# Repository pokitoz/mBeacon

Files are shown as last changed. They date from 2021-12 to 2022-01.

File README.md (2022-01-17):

# mBeacon

mBeacon

## Antenna

- No angle on the trace
- Vias should surround the track and the antenna to apply a shielding
- It is best to avoid the use FR4 stack layer
  - As this is not controled and epsilon can vary. 
  - HR370 isola is better to control the impedence

To check the 50Ohm, use the too AppCAD or https://saturnpcb.com/saturn-pcb-toolkit/
- Go to `Tools > DRC...` 
- find layer stack in eagle..
- copper is selected when ordering. Check the manufacturer webite: https://jlcpcb.com/capabilities/Capabilities
- stack manager: Isolation height and copper height Track height.

## Manufacturing

- File > Generate CAM data
  - Export to .zip and upload to manufacturing site
- For jlcpcb, BOM and CPL needs to be generated: https://support.jlcpcb.com/article/132-how-to-generate-bom-and-cpl-from-eagle-cad-automatically

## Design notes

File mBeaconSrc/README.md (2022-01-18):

# mBeacon

## Project setup

- Do not have Spaces in the path of the project
- Based on platformio: `https://platformio.org/install/ide?install=vscode`, use VSCode and import the project
- Zephyr version can be found in `C:\.platformio\packages\framework-zephyr\VERSION`.
- Look for `https://docs.platformio.org/en/latest/frameworks/zephyr.html?utm_source=docs.zephyrproject.org#configuration`
  To get more details on how to configure the workspace.
- `make menuconfig`, if arrows do not work, use "j" and "k".

## Run the program

Logs can be extracted using J-Link RTT viewer
It won't start until it is connected. Configuration is nRF52832_xxAA

## Files

zephyr: contains all the necessary information for the OS:

- DTS overlay for adding the support of the sensors
- conf: For adding or removing some parts of the OS
- Contains the main top level CMake file

src: Source of the project, all the .c files (from platform IO)

include: Includes of the project, all the .h files (from platform IO)

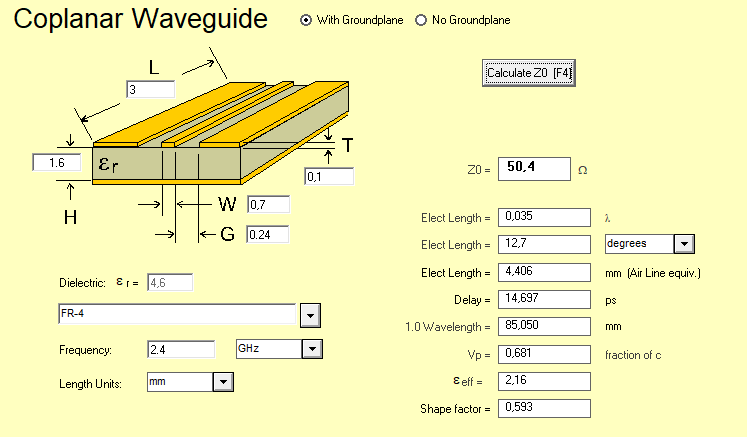
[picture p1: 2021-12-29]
coplanar.png

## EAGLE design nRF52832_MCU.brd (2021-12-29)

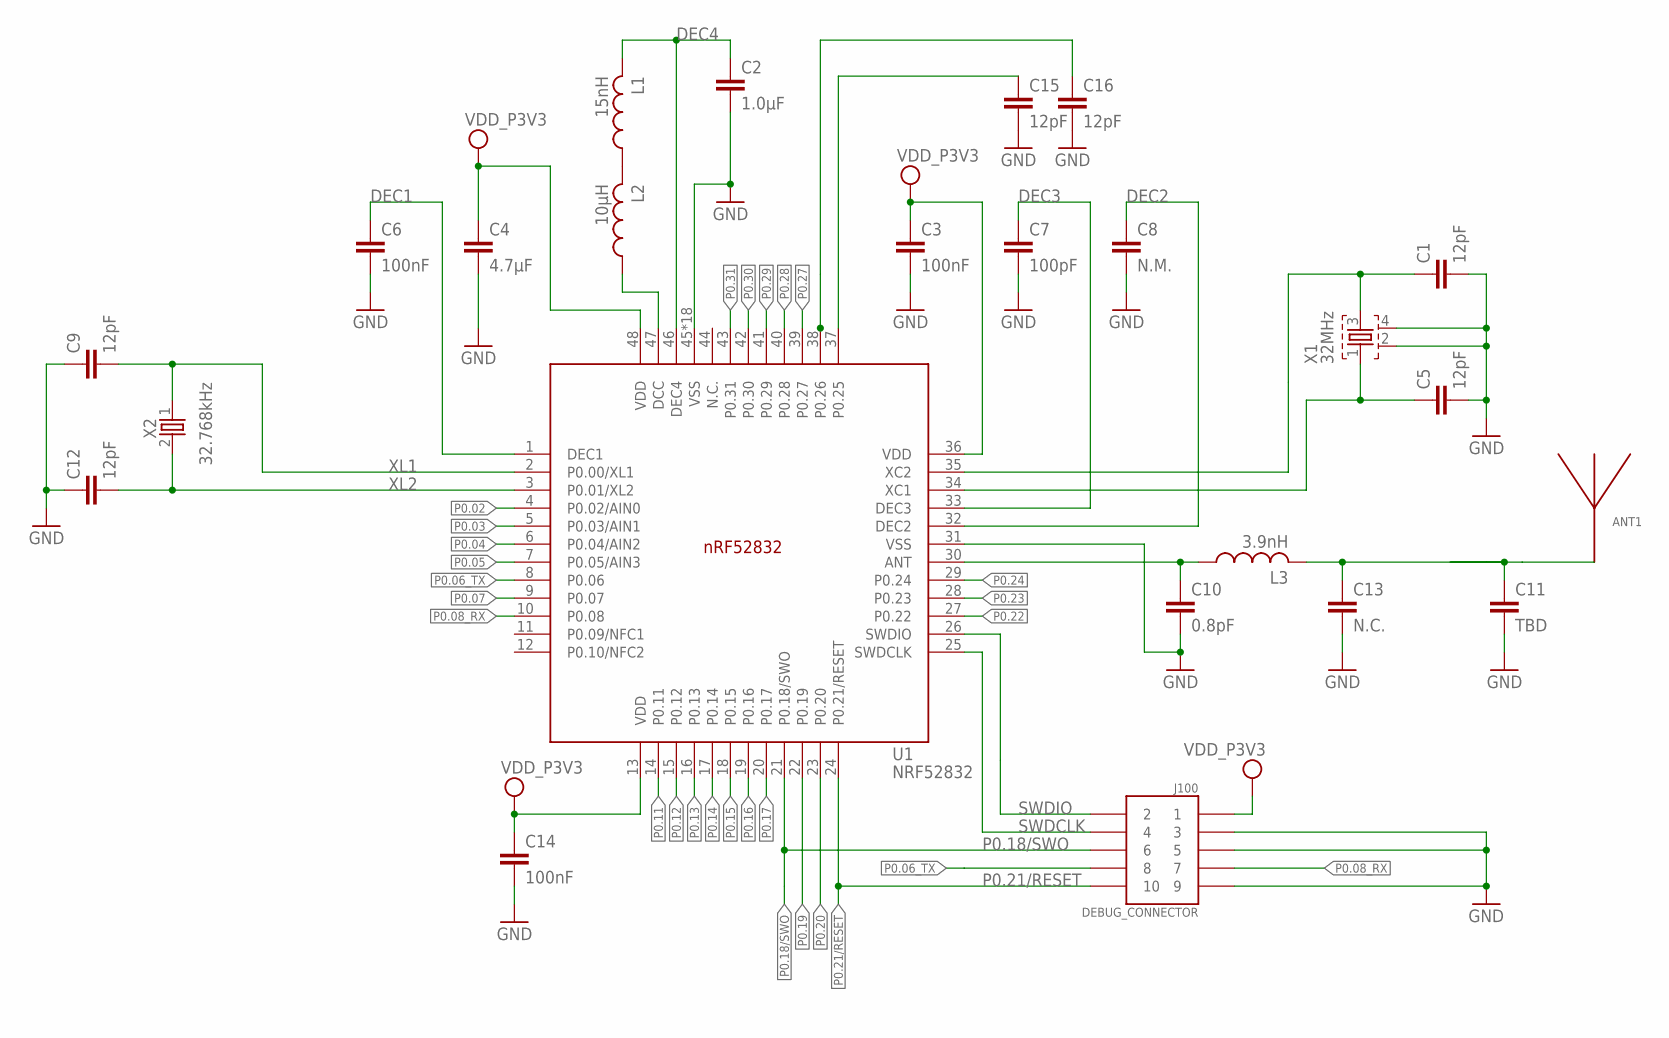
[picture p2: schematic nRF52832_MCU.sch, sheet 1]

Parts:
ANT1: ANTENNA_QUARTER-WAVE_MONOPOLE_MEANDERED_LEFT; QWMP_MEANDERED_LEFT_+6
C1, C5, C9, C12, C15, C16: 12pF; RESC0402_N
C2: 1.0µF; RESC0603_N
C3, C6, C14: 100nF; RESC0402_N
C4: 4.7µF; RESC0603_N
C7: 100pF; RESC0402_N
C8: N.M.; RESC0402_N
C10: 0.8pF; RESC0402_N
C11: TBD; RESC0402_N
C13: N.C.; RESC0402_N
J100: DEBUG_CONNECTOR; HDRV127P5X2-10_N
L1: 15nH; RESC0402_N
L2: 10µH; RESC0603_N
L3: 3.9nH; RESC0402_N
U1: NRF52832; QFN40P600X600X90-48_N
X1: 32MHz; BT-XTAL_2016_N
X2: 32.768kHz; XTAL_3215_N

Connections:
ANT: C10.1, L3.1, U1.30 (ANT)
DEC1: C6.1, U1.1 (DEC1)
DEC2: C8.1, U1.32 (DEC2)
DEC3: C7.1, U1.33 (DEC3)
DEC4: C2.1, L1.2, U1.46 (DEC4)
unnamed: L1.1, L2.2
unnamed: C1.1, U1.35 (XC2), X1.3
unnamed: L2.1, U1.47 (DCC)
unnamed: ANT1.P$1, C11.1, C13.1, L3.2
unnamed 14: C1.2, C2.2, C3.2, C4.2, C5.2, C6.2, C7.2, C8.2, C9.1, C10.2, C11.2, C12.1, C13.2, C14.2, C15.2, C16.2, J100.3, J100.5, J100.9, U1.31 (VSS), U1.45 (VSS), U1.PAD (VSS), U1.PAD@VIA01 (VSS), U1.PAD@VIA02 (VSS), U1.PAD@VIA03 (VSS), U1.PAD@VIA04 (VSS), U1.PAD@VIA05 (VSS), U1.PAD@VIA06 (VSS), U1.PAD@VIA07 (VSS), U1.PAD@VIA08 (VSS), U1.PAD@VIA09 (VSS), U1.PAD@VIA10 (VSS), U1.PAD@VIA11 (VSS), U1.PAD@VIA12 (VSS), U1.PAD@VIA13 (VSS), U1.PAD@VIA14 (VSS), U1.PAD@VIA15 (VSS), U1.PAD@VIA16 (VSS), X1.2, X1.4; also elsewhere on the board
P0.02: U1.4 (P0.02/AIN0)
P0.03: U1.5 (P0.03/AIN1)
P0.04: U1.6 (P0.04/AIN2); also elsewhere on the board
P0.05: U1.7 (P0.05/AIN3); also elsewhere on the board
P0.06_TX: J100.8, U1.8 (P0.06)
P0.07: U1.9 (P0.07); also elsewhere on the board
P0.08_RX: J100.7, U1.10 (P0.08)
P0.11: U1.14 (P0.11)
P0.12: U1.15 (P0.12)
P0.13: U1.16 (P0.13); also elsewhere on the board
P0.14: U1.17 (P0.14); also elsewhere on the board
P0.15: U1.18 (P0.15)
P0.16: U1.19 (P0.16)
P0.17: U1.20 (P0.17)
P0.18/SWO: J100.6, U1.21 (P0.18/SWO)
P0.19: U1.22 (P0.19)
P0.20: U1.23 (P0.20)
P0.21/RESET: J100.10, U1.24 (P0.21/RESET)
P0.22: U1.27 (P0.22)
P0.23: U1.28 (P0.23)
P0.24: U1.29 (P0.24)
P0.25: C15.1, U1.37 (P0.25)
P0.26: C16.1, U1.38 (P0.26)
P0.27: U1.39 (P0.27)
P0.28: U1.40 (P0.28)
P0.29: U1.41 (P0.29)
P0.30: U1.42 (P0.30)
P0.31: U1.43 (P0.31)
SWDCLK: J100.4, U1.25 (SWDCLK)
SWDIO: J100.2, U1.26 (SWDIO)
VDD_P3V3: C3.1, C4.1, C14.1, J100.1, U1.13 (VDD), U1.36 (VDD), U1.48 (VDD); also elsewhere on the board
X1: C5.1, U1.34 (XC1), X1.1
XL1: C9.2, U1.2 (P0.00/XL1), X2.1
XL2: C12.2, U1.3 (P0.01/XL2), X2.2

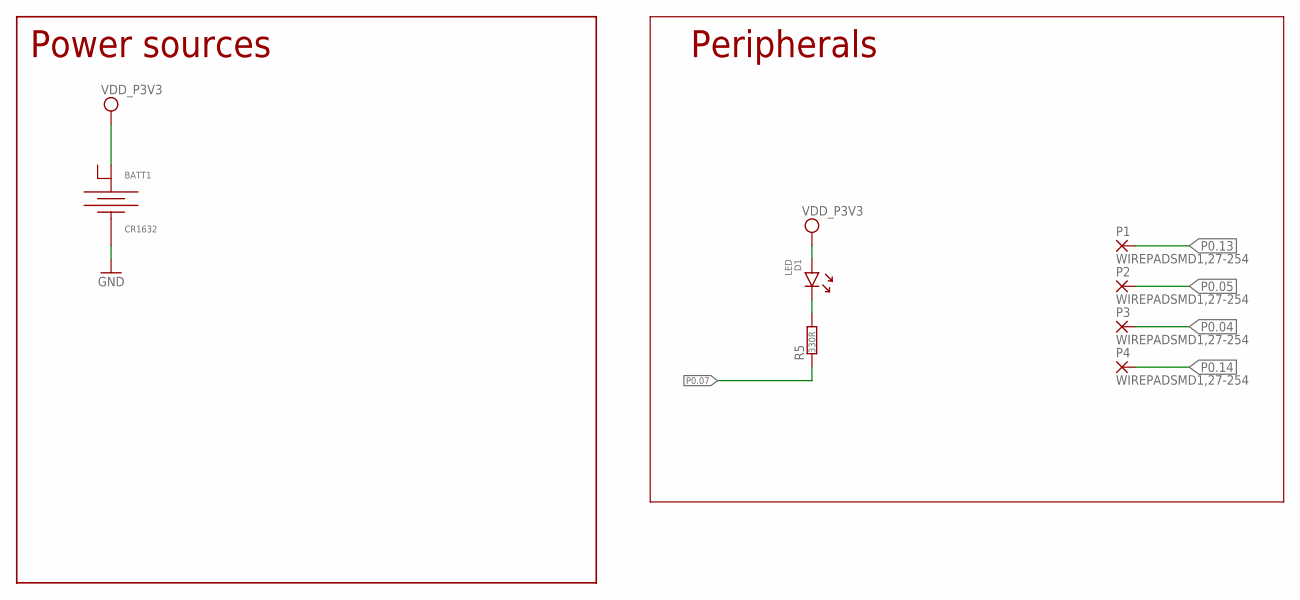
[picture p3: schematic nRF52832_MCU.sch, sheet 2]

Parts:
BATT1: CR1632; CR1632_HOLDER_TH
D1: LED; DIOC0603_N
P1, P2, P3, P4: WIREPADSMD1,27-254; SMD1,27-2,54
R5: 330R; RESC0402_N

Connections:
unnamed: D1.1 (C), R5.2
unnamed 14: BATT1.1 (-); also elsewhere on the board
P0.04: P3.1; also elsewhere on the board
P0.05: P2.1; also elsewhere on the board
P0.07: R5.1; also elsewhere on the board
P0.13: P1.1; also elsewhere on the board
P0.14: P4.1; also elsewhere on the board
VDD_P3V3: BATT1.2 (+), D1.2 (A); also elsewhere on the board

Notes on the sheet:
Power sources
Peripherals

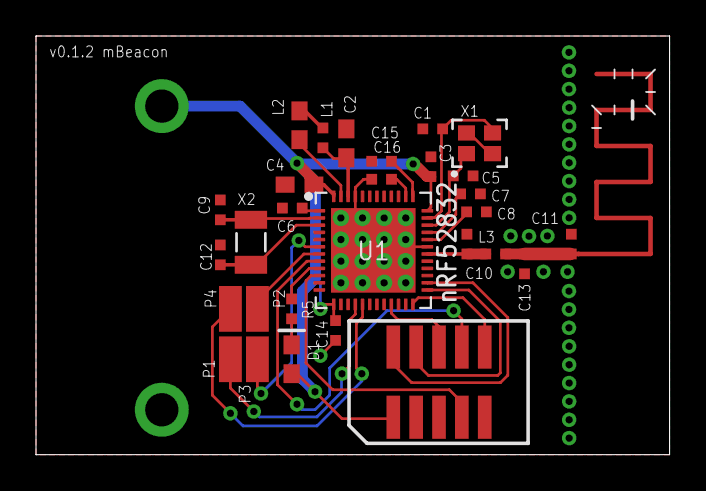
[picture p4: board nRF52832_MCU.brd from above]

Board: 2 copper layers, 35.2 x 23.3 mm, 31 parts (1 on the bottom side), 28 nets.

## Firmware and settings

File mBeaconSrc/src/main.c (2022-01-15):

#include <zephyr.h>
#include <sys/printk.h>
#include <device.h>
#include <drivers/gpio.h>
#include <bluetooth/bluetooth.h>
#include <bluetooth/hci.h>

#define DEVICE_NAME CONFIG_BT_DEVICE_NAME
#define DEVICE_NAME_LEN (sizeof(DEVICE_NAME) - 1)

#define LED0_NODE DT_ALIAS(led0)

#if DT_NODE_HAS_STATUS(LED0_NODE, okay)
#define LED0  DT_GPIO_LABEL(LED0_NODE, gpios)
#define PIN  DT_GPIO_PIN(LED0_NODE, gpios)
#define FLAGS  DT_GPIO_FLAGS(LED0_NODE, gpios)
#else
#error "No LED0"
#endif
#define MIN_PERIOD_USEC  (USEC_PER_SEC / 64U)
#define MAX_PERIOD_USEC  USEC_PER_SEC
#define SLEEP_TIME_MS   1000

static uint8_t mfg_data[] = {
  0xda, 0x09, // Nagra ID code
  0x64, // Battery level
  0xFF, 0xFA, 0xAC, 0xFF, 0xDE, 0xAD, // Mac
  'A', 'n', 'T', 'Z', 'o', 'n', '-', 'E', '8', // Whitelist
  0xb0, 0x01
};


// Advertizing should be on 31 bytes max
static struct bt_data ad[] = {
  BT_DATA_BYTES(BT_DATA_FLAGS, (BT_LE_AD_GENERAL | BT_LE_AD_NO_BREDR)),
  BT_DATA_BYTES(BT_DATA_UUID16_ALL, 0xFF, 0xF1),
  BT_DATA(BT_DATA_MANUFACTURER_DATA, mfg_data, sizeof(mfg_data))
};

/* Set Scan Response data */
static const struct bt_data sd[] = {
  BT_DATA(BT_DATA_NAME_COMPLETE, DEVICE_NAME, DEVICE_NAME_LEN),
};

static void bt_ready(int err)
{
  char addr_s[BT_ADDR_LE_STR_LEN];
  bt_addr_le_t addr = {0};
  size_t count = 1;

  if (err) {
    printk("Bluetooth init failed (err %d)\n", err);
    return;
  }

  printk("Bluetooth initialized\n");

  /* Start advertising */
  err = bt_le_adv_start(BT_LE_ADV_NCONN_IDENTITY, ad, ARRAY_SIZE(ad),
            sd, ARRAY_SIZE(sd));
  if (err) {
    printk("Advertising failed to start (err %d)\n", err);
    return;
  }

  bt_id_get(&addr, &count);
  bt_addr_le_to_str(&addr, addr_s, sizeof(addr_s));

  printk("mBeacon started, advertising as %s\n", addr_s);
}

void main(void)
{
  const struct device *dev;
  bool led_is_on = true;
  int ret;

  dev = device_get_binding(LED0);
  if (dev == NULL) {
    return;
  }

  ret = gpio_pin_configure(dev, PIN, GPIO_OUTPUT_ACTIVE | FLAGS);
  if (ret < 0) {
    return;
  }

  int err = bt_enable(bt_ready);
  if (err) {
    while (1) {
      gpio_pin_set(dev, PIN, (int)1);
    }
  }

  while (1) {
    gpio_pin_set(dev, PIN, (int)led_is_on);
    led_is_on = !led_is_on;
    k_msleep(SLEEP_TIME_MS);
    printk("Alive!\n");
  }
}

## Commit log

2021-12-20 Add first design eagle mBeacon
    [nRF52832_MCU.brd, nRF52832_MCU.sch]
2021-12-20 Add missing capacitors
    [nRF52832_MCU.brd, nRF52832_MCU.sch]
2021-12-21 Update rastnest
    [nRF52832_MCU.brd]
2021-12-21 Add info on PCB antenna trace
2021-12-21 Add additional pin connector
    [nRF52832_MCU.brd, nRF52832_MCU.sch]
2021-12-21 Fix warnings on layout
    [nRF52832_MCU.brd]
2021-12-28 Antenna airwire without detour
    [nRF52832_MCU.brd]
2021-12-28 Update dec capacitor orrientation
    [nRF52832_MCU.brd]
2021-12-28 Update labels and restrict masks
    [nRF52832_MCU.brd]
2021-12-28 Remove DRC errors
    [nRF52832_MCU.brd]
2021-12-29 Add board version
    [nRF52832_MCU.brd]
2021-12-29 Add space for further devices
    Accelerometer, pressure,..
    [nRF52832_MCU.brd]
2021-12-29 Make sure rastnest is around battery
    [nRF52832_MCU.brd]
2021-12-29 Add instruction for BOM and jlcpcb
2021-12-29 Same size signal for antenna link
    [nRF52832_MCU.brd]
2021-12-29 Add coplanar computation
    [nRF52832_MCU.brd, nRF52832_MCU.sch]
2022-01-15 Updated nrf52 board for mBeacon board
